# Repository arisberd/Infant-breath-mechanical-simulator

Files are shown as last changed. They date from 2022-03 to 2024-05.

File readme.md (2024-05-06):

# Infant breath mechanical simulator

This project is about building, developing, documenting and using a mechanical breathing simulator. The device simulates airflow conditions observed in either normal infants or those experiencing respiratory diseases. Simulating airflows is used in laboratory conditions for research and experimentation in areas such as flow dynamics, neonatology and respiratory medicine. 

# Features
- High volume and flow accuracy
- Easily expandable in software and hardware (ex. child or adult volumes, advanced respiratory patterns, etc)
- Low construction cost using simple hardware equipment (ex. stepper motors, arduino, etc)

# Main modules
- The volume compartment consists of a calibration syringe for respiratory equipment
- Air flow is produced from a moving carriage by a stepper motor
- Arduino is used for software and data, with a simple interaction with computer's Serial Monitor 
- Some hardware parts are 3d printed, and based on [RepRap Prusa Interation 3](https://reprap.org/wiki/Prusa_i3)

# Documentation
You will find documentation for construction, configuration and usage under [Documentation/doc.md](https://github.com/arisberd/Infant-breath-mechanical-simulator/blob/main/Documentation/doc.md). 

# Version 0.3
This is a developing project, but fully functional on predefined settings. You may encounter problems while using new features or trying to modify functions.

# Contribution
This project started at Pediatric Pulmonology Department of University Hospital of Patras, Greece at 2021. Feel free construct the device, use it or contribute to the project. [Questions and comments](https://github.com/arisberd/Infant-breath-mechanical-simulator/issues) are welcome.

# License
This project is licensed under [GNU GPL v3](https://www.gnu.org/licenses/gpl-3.0.html)

# Credits
We would like to thank major contributors _S.Fouzas, O.Tsakiridis, D.Monopatis_, and also RepRap and Prusa communities.

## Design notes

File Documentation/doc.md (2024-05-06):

# Documentation of Infant Breath Mechanical Simulator

Construction and use

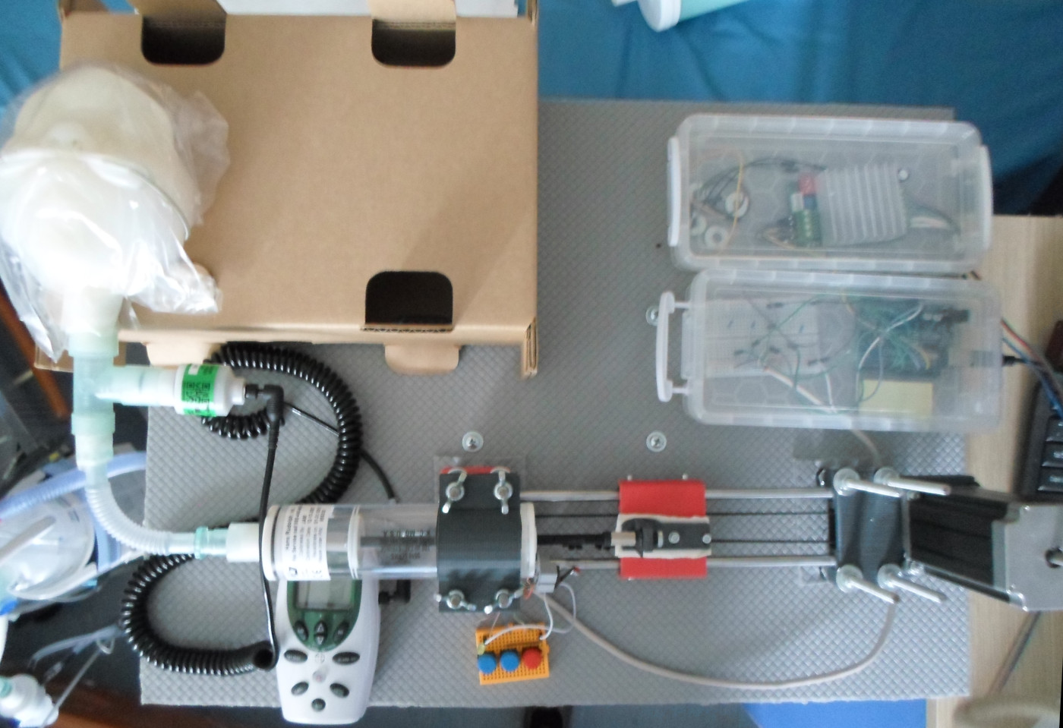
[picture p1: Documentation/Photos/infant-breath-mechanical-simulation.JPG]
 

[https://github.com/arisberd/Infant-breath-mechanical-simulator](https://github.com/arisberd/Infant-breath-mechanical-simulator)

version 0.2

GNU GPL v3

## Table of contents

[TOC]

## General

Infant breath mechanical simulator is a low-tech device designed to facilitate respiratory experiments. Its hardware design is primarily based on RepRap Prusa Interation 3, specifically utilizing its X-axis components. Therefore, the majority of the hardware components are similar to that of a typical 3d printer with a single axis. The device is powered and controlled using  Arduino electronics, providing precise motor movement and enabling computer communication.

# Getting Started

## Project's origin

This is a developing project and was initiated in the Pediatric Department of University Hospital of Patras, Greece in 2021. While this documentation provides comprehensive instructions for construction and use, please be aware that this is a developing project, so issues may arise. 

## Required skills:

To successfully operate this project, you should possess a basic understanding of the following:

* 3d printing: familiarity with 3d printing techniques, equipment and slicing
* Arduino electronics: basic skills of Arduino wiring and program uploading
* Software skills: basic software skills during the first setup, in order to configure the program file

## Community Collaboration

We encourage you to participate in and contribute to the project's development under GPL3 lincense. If you have questions or insights, feel free to contact with [project's community](https://github.com/arisberd/Infant-breath-mechanical-simulator/issues).

### Bill of materials

Electronics:

* Arduino Uno
* Stepper Motor Driver (TB6600A used)
* DC Power supply (24 volt used)
* Breadboard Buttons (2 blue, 1 red)
* Arduino wires, resistants and breadboards

Mechanical Components:

* Stepper Motor 56mm, high torque motor (Wantai NEMA 23 used, 30kg.cm)
* GT2 Gear (40teeth)
* GT2 Belt
* Endstop switch
* Linear bearing 8mm (4 pieces)
* Ball bearing 3mm inner diameter (2 pieces)
* Rods 8mm (2 pieces)
* Wooden frame at least 30 X 40 cm
* Callibration syringe (100ml or 1000ml)

Fasteners:

* M3 bolts and nuts
* M4 bolts and nuts
* M8 bolts and nuts
* A double nut (only at Hole method)

3D printing:

* PLA/PET 3d print filament

## Printing parts

### Overview

In this section you can find 3d-printed STL files required for assembling Infant Breath Mechanical Simulator. These file are available in the `3d_printed_parts/Stl rendered files` folder. These stl files are rendered based on [openscad](http://openscad.org/downloads.html) files, where customization can be made. `Compact_endstop.stl` is made and downloaded by `https://www.thingiverse.com/chri/designs`. 

### 3d Slicing preparation

Before 3d printing, it's vital to prepare the STL file, using a slicing software. We recommend [Prusa Slicer](https://www.prusa3d.com/page/prusaslicer_424/). Printing at `layer height 0.3mm` and `nozzle 0.4mm` was found decent.

### List of 3d-printed files:

* `Axis based on x-end.stl` this file contains 3 models for the one-axis static compartment.
* `x-carriage.stl` is the moving part on the rods.
* `compact_endstop.stl` this part hosts the endstop switch.
* `syringe_attacher_with_flange.stl` and `syringe_attacher_only_the_flange.stl` are used for grapping the syringe with a flange system. Otherwise you can use next file:
* `syringe_attacher_with_hole.stl` this file secures syringe by using a hole and a double nut
* `syringe_base_100ml.stl` mounts a 100ml syringe. You should print at least a pair of them for stability
* `syringe_base_1000ml.stl` mounts a bigger (1000ml) syringe. Again at least a pair of them is needed.

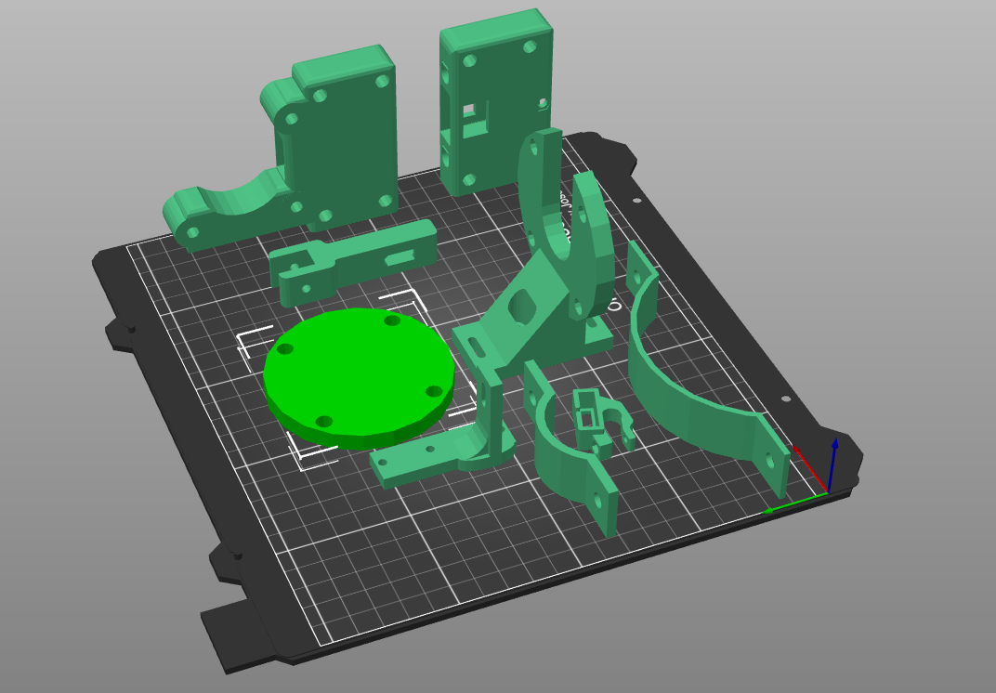
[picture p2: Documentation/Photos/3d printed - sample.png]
 

## Flange or hole method

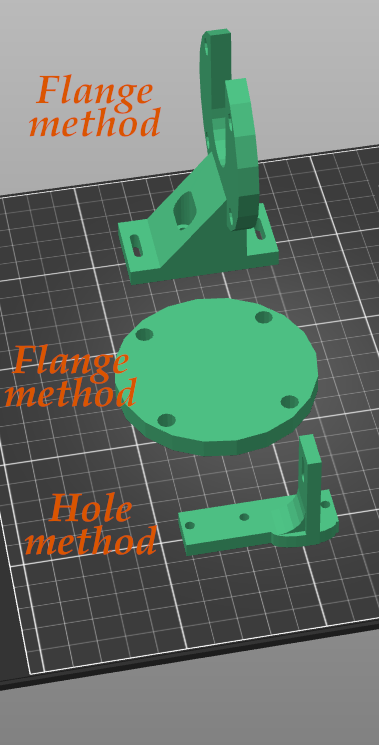
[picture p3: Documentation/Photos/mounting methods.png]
 

There are two methods for attaching the syringe's plunger on the machine: 

* The **flange method** involves using two printed parts to secure plunger's *hand* in place. This method is suitable for calibration syringes where the plunger's hand cannot be detached. Place the plunger's hand between the two 3D-printed parts and use M8 bolts and nuts for securing all together . We used a **1000ml syringe** with this method. 

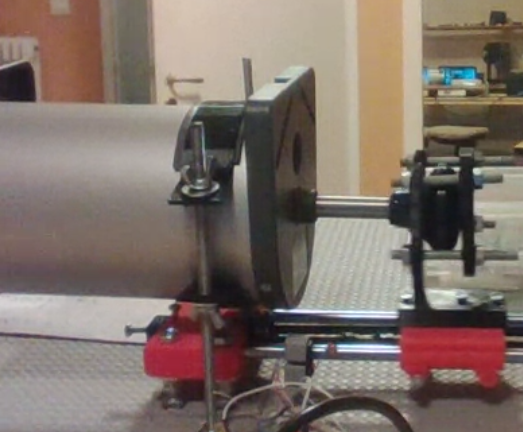
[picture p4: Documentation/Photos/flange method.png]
 

* The **hole method** is used when the syringe's piston has a threaded end, and the plunger's hand can be unscrewed. With this method, only one 3D-printed part is used. A double nut is used to secure the plunger to the 3d print part. We used a **100ml syringe** with this method.

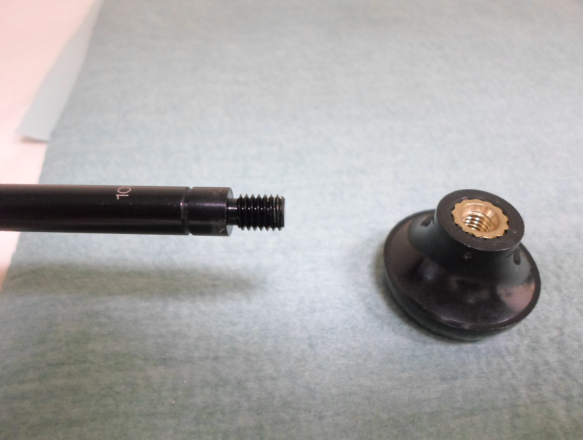
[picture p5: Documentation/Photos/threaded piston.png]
 
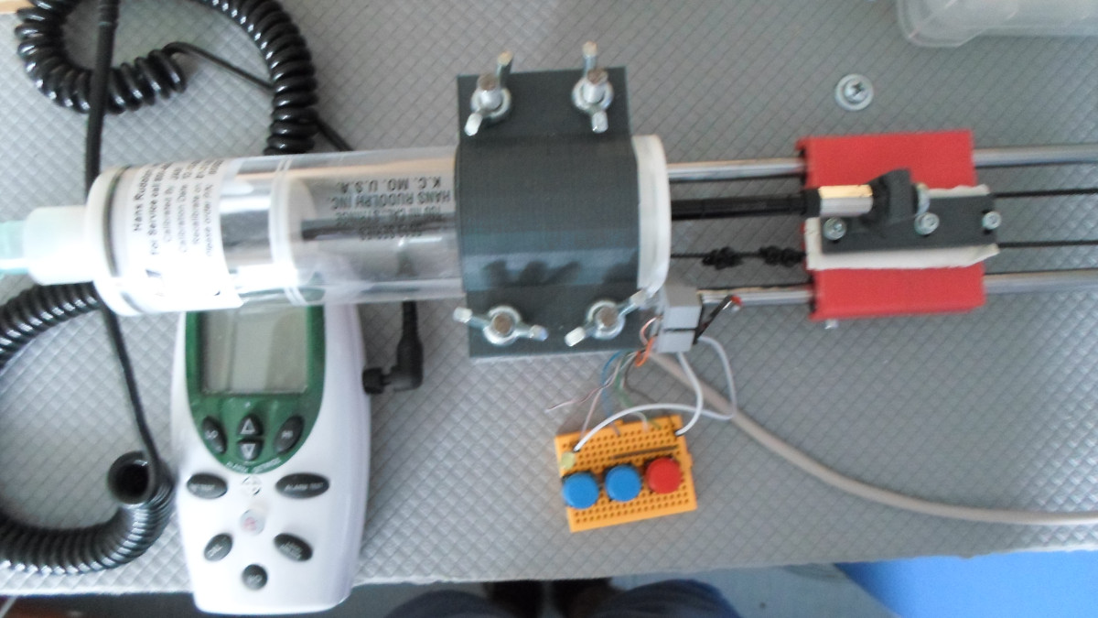
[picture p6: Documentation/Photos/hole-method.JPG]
 

## Electronics

Basic module of the project is an [Arduino Uno](https://store.arduino.cc/products/arduino-uno-rev3). Wiring is shown in the following photo:

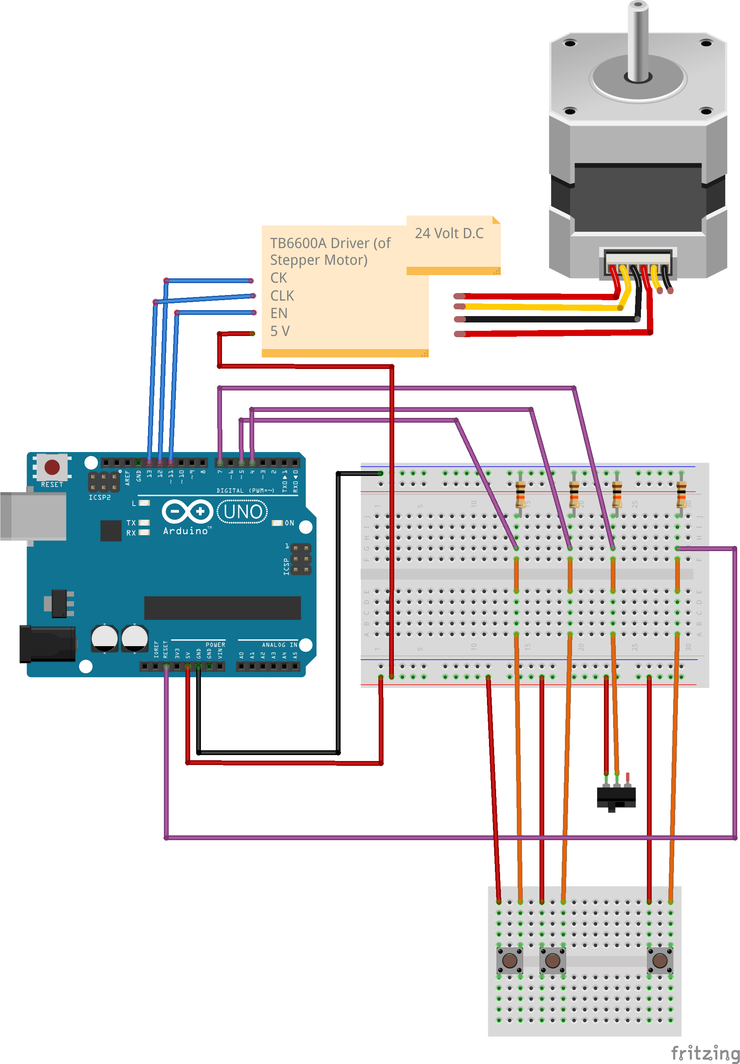
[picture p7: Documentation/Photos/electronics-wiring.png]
 
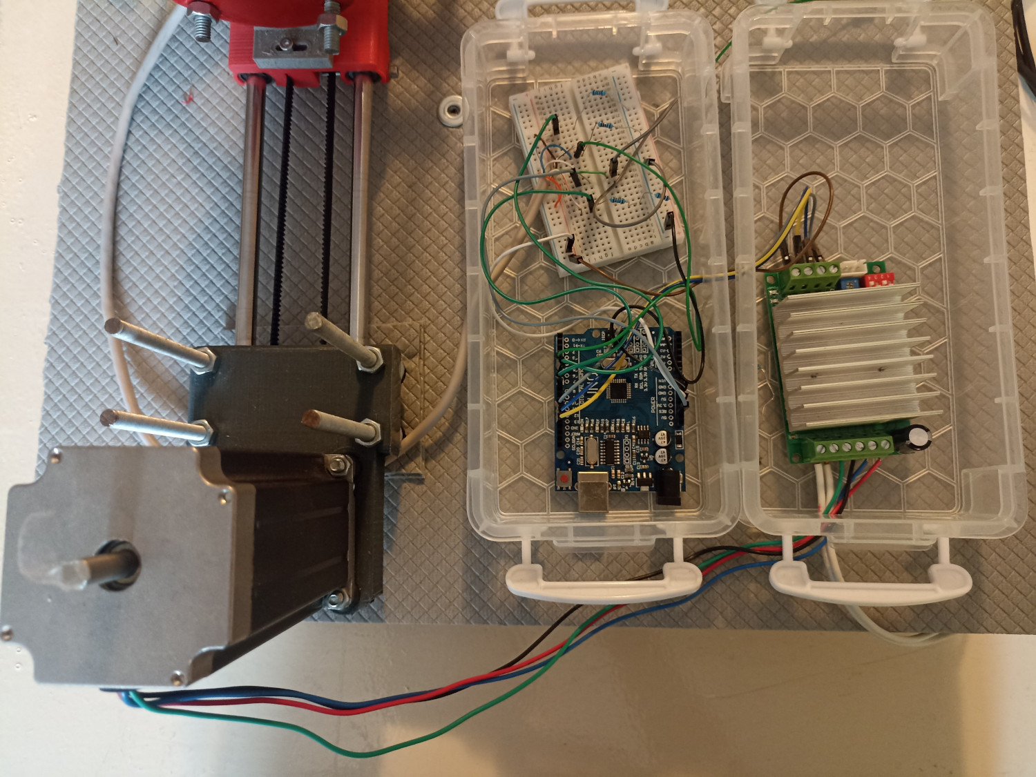
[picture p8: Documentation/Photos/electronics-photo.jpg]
 

* The motor's Driver (TB6600A) is connected at arduino digital pins as shown. Driver also connects to a 24 Volt DC current as well as the Stepper Motor. Be sure to adjust Driver's current sparingly, starting at very low currents and slowly increase at first test. Low current will give low torque to the motor, making it not to move at high speed requirements. High current gives high torch, making driver hot and appling lot of torque at the speed changes. You should also check the microstepping setting. The software's default is 1/8 microstepping (can be changed in software, too). At the following pictures, the arrow show the microstepping switches. We used 8 microsteps. Refer to the datasheet for choosing the correct combination for microstepping.

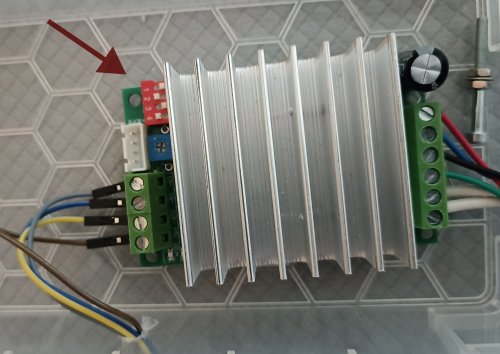
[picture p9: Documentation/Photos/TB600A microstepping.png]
 
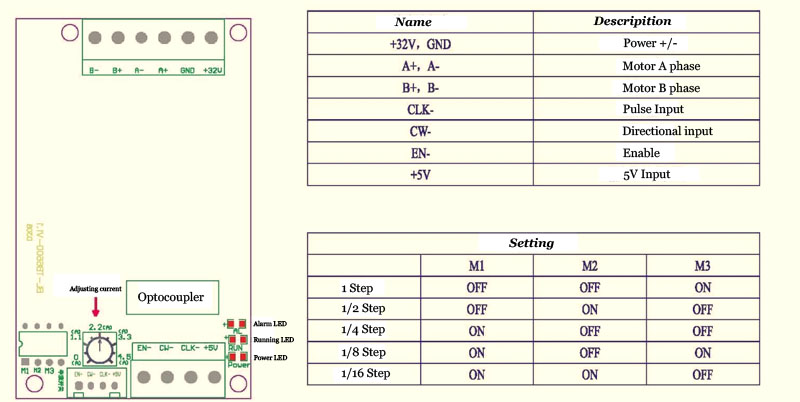
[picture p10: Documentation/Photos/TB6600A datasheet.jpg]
 

* Endstop and Buttons are connected as shown in the picture. A wire extension should be used. Note at endswitch should be connected as open-circuit when not pressed. At the following picture an ethernet cable extension is used (contains 8 wires). Note that the blue button No1 is used for changing rows in the experiment, whereas the blue botton No2 is used for pause. Red button is used for hardware reset, and is connected to the reset button of the arduino.

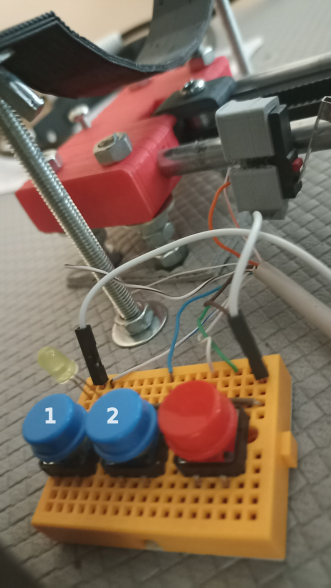
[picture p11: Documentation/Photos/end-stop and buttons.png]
 

Note that both 5 Volt and 24 Volt D.C. circuits are used in this project. 24 Volt is only used at motor's Driver, whereas the 5 Volt is used at almost all modules. The 5 Volt can be produced either by the USB of arduino or direct arduino power. 

## Hardware assembly

NOTE: This project is based on RepRap Prusa Interation 3, as a modified X axis. More instructions based on a x-axis of a 3d printer can be found [here](https://reprap.org/wiki/RepRapPro_Huxley_x_axis_assembly), but use this guide for reference only, as many things are not similar.

1.Frame Setup:

A wooden frame of at least 30 X 40 cm should be used as a base. This frame will hold things together. The way to fix them in place is using M8 bolts and nuts on 3d-printed parts.

2.Thightener:

Start by assembling the `tightener`, which is the small part of the `Axis based on x-end.stl`. This part is crucial for tighten the belt more that can be done by hand. Put a M3 bolt and nut so that the 2 ball bearings hold together at the end of the `tightener`. Put another M3 (or M4) bolt on the other side. This bolt is going to adjust the tension.

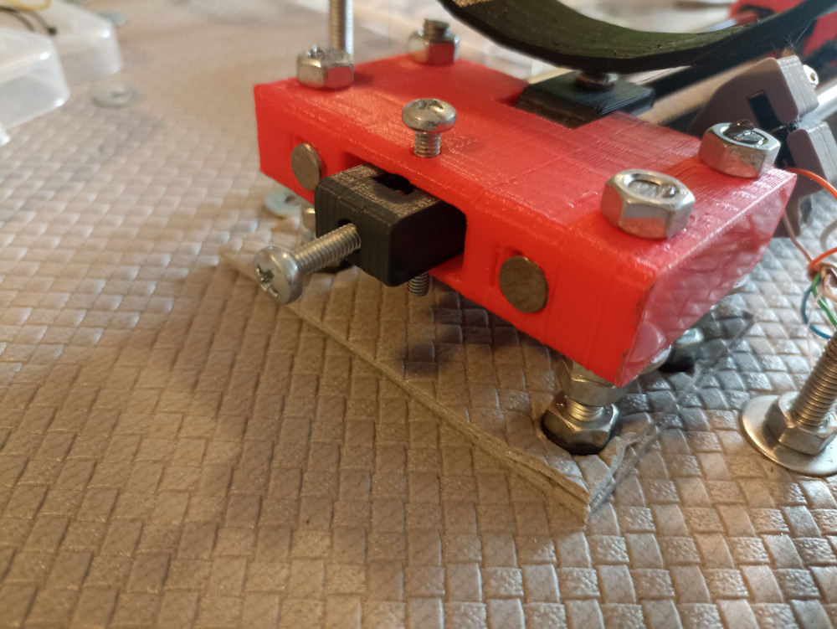
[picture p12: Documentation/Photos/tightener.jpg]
 

3.Carriage assembly and Axis: 

Then you should assembly the `x-carriage.stl`. Belt is attached to this piece so it can be moved up and down on the rods. A second 3d-printed piece will hold the plunger of the syringe, and will be attached upon `carriage`. Start by fitting the 4 linear bearings (3 can also be used) and secure the with M3 bolts and nuts. Attach the one side of the belt at the slot under the `x-carriage.stl`. The other side is to be attached later. Insert the rods to the linear bearing taking care not to damage the bearing. On either side of the rods attach the rest parts of the `Axis based on x-end.stl` by pushing the rods gently. Then you should choose of the two methods of plunger attachment : flange method or hole method. Read also `Flange of hole method`. Take the appropriate 3d-printed part and secure it on `carriage` using three M3 bolts and nuts.  This will appear like the following photo:

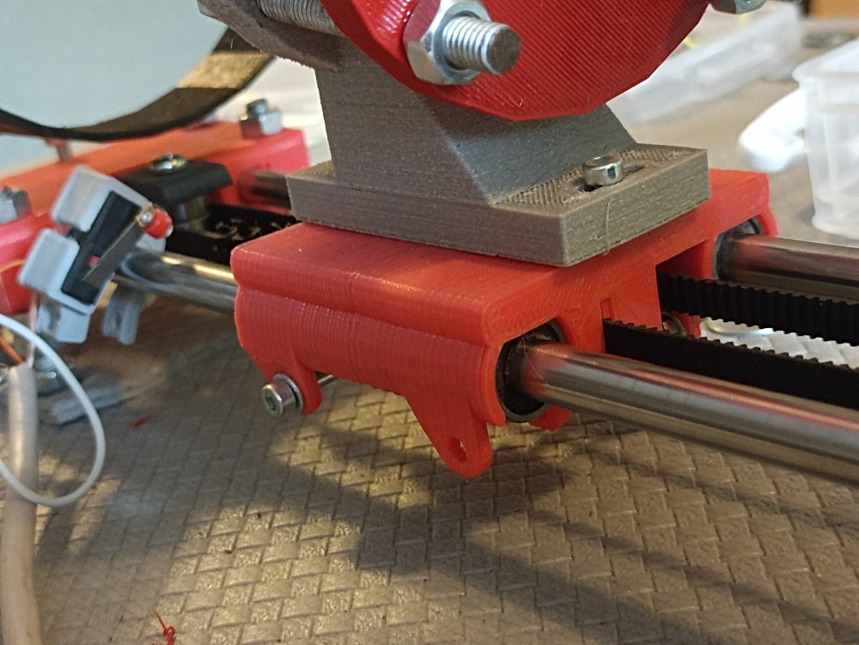
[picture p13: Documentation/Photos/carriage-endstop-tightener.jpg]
 

4.Securing to Wooden Frame:

The two 3d-printed sides of apparatus should be now fixed to the wooden frame. Using M8 bolts and nuts thighten up and fix the in place. 

5.Stepper Motor install:

Fit the 56mm Stepper Motor and secure it using M4 bolts and nuts. Attach the gear and tighten its bolt.

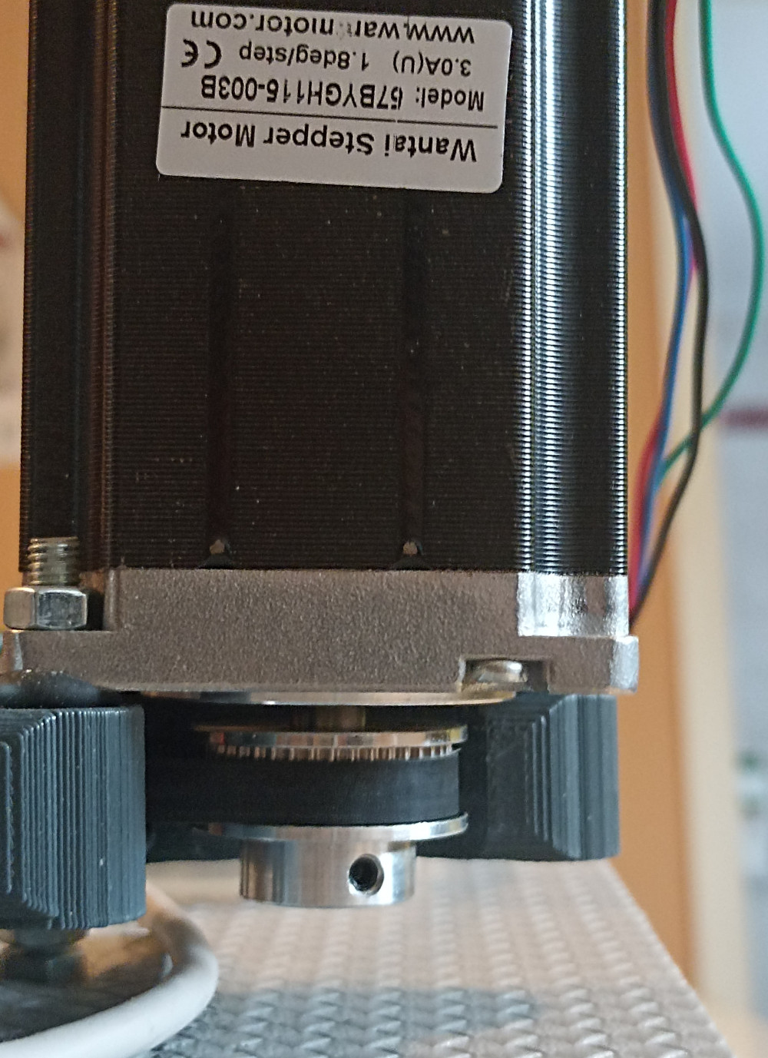
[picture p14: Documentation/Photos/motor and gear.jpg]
 

6.End-stop switch:

Using end-stop switch the system can understand the starting position of the syringe. This is usually a position with little starting air volume. Attach the end-stop switch in the left side of a rod and rotate it so carriage can press the switch button when moved. You can secure the switch with M3 bolts and nuts, or do this job later, in order to test accurate starting volume. 

7.Belt:

Put on the `thightener` at the one side of the apparatus. Pull the belt under the gear at one side and under the `thightener`'s bearings on the other. Then pull belt back under the carriage and fix it properly. Make this first by hand as tight as possible and then tighten more using the side bolt of the `tightener`.

8.Securing syringe:

After reading **Flange or hole method**, choose your printing file between `syringe_base_100ml.stl` and `syringe_base_1000ml.stl`. You will need at least one pair of these. Attach one of the printed files to the wooden frame using M8 bolts and nuts. Take care that bolts are long enough: put the syringe on printed-base and on-top put a second printed-base. Using the same bolt secure wooden frame to both printed parts. You can use a second pair of printed parts to secure syringe in the other side.

 
 

9a. **Flange mode** - Securing the plunger:

Bring all pieces in place: the `syringe_attacher_with_flange.stl` then the handle of the plunger and then the `syringe_attacher_only_the_flange.stl`. These 3 are going to be secured using M8 bolts and nuts. Secure them one by one, taking care not to be very tighted and damage the handle, whereas not being to loose.

9b. **Hole method** - Securing the Plunger:

Things are going to be more stable using the hole method. A long nut at the size of plunger's bolts is going to be needed. First attach this nut at the plunger and then using another bolt, through the 3d printed file syringe_attacher_with_hole.stl. Secure things together.

 

### Beyond Syringe

The syringe can move air to any other compartment. During first setup, an model of infant airway was used as showed in the following photo.

 

### Final hardware aspects

Your hardware setup is ready by this point. Before proceding to software installation and first run, take care to examine all moving parts in order or avoid damage due to misuse:

* Check the belt to be tight enought,

* Move the carriage with your hand slow enough and check if the piston of the syringe move smoothly, in a complete linear movement. It should not take any vertical forces.

* Check the position of carriage when moved and press the end-stop switch, so it does not damage the syringe.

* If using flange method, the handle must be tighted locked between the 3d printed parts and check if as it moves, so it does not get damage. 

## Software

### Arduino IDE

Each specific movement of the carriage will produce distinct respiratory cycle and this is going to be configured through software. Arduino is used not only to control all electronics but also to manage data. To get started, you will need the Arduino software, known as [Arduino IDE](https://www.arduino.cc/en/Guide). This computer software enables to upload programs to Arduino board. Here are the steps:

1. **Download Arduino IDE**: visit the [Arduino IDE download page](https://www.arduino.cc/en/software) to download the software.

2. **Configuration Guide**: Take some time to feel comfortable with Arduino IDE and review the available [documentation](https://www.arduino.cc/en/Guide). This will help you understand how Arduino IDE communicates with Arduino board, including which ports you will need to use and how to select the appropriate Arduino board.

3. **Opening the project's file**: Though Arduino IDE, open the `breath-sim.ino` file of the project. This file contains the code necessary to control arduino board. At this step you don't need to open datasheets that are stored in different files. 

4. **Uploading to Arduino Board**: Connect your Arduino board to your computer using a USB cable. In Arduino IDE, select the correct port and Arduino Board Model and click the *Upload* button. If everything is set corrrectly, then a message will be shown in Arduino IDE terminal to configure a successful upload.

5. **Serial Monitor**: After uploading, you can use Serial Monitor to monitor Arudino's function and send commands. You can open it from Arduino IDE, as long as USB is connected and a prompted upload has been done.

### Data

Data for is stored in seperated files that work as datasheets. By default, `dataleo2.h` is used for this purpose. The data is stored in specific format as outlined in the beggining of datasheet files. These include:

* **VT** (Volume Tidal): this represent the amount of air in **milliliters** (ml) moved in a single breath

* **Ti** (Time of Inspiration): this indicates the time in **milliseconds** of the inspiration phase

* **Te/Ti ratio** (Time of Expiration to Time of Inspiratio ratio): this ratio defines the duration of expiration compared to duration of inspiration, expressed as a percentage. 

All values in datasheets are seperated by commas (,). Each set of these data values forms a row, which corresponds to a specific respiratory cycle. For example in `dataleo2.h`, the first row reads as follows: `80  , 300 , 185 ,`. This configuration results in a respiratory cycle of 80ml, with inspiration time of 300 msec and Te/Ti ratio of 185%. By using mathimatical calculations, you can derive expiration time, which is 555msec in this example, and respiratory rate which is 70/sec. 

You can navigate through different respiratory profiles, by pressing blue button No. 1, which allows you to switch to next rows in the datasheet. In `dataleo2.h` the second row is `80  , 300 , 150 ,`  and differs in Te/Ti ratio only. `Dataleo2.h` datasheet is based on typical breathing parameters for infants.

## Configuration setup before first run

Now its time for your first run! You should check the following list before first run and do some callibration. If you make changes in datasheets or `breath-sim.ino` file, make sure you upload it again. All you will need to configure appear in the first code lines of `breath-sim.ino`. Open it with Arduino IDE and check the values as follows:

### `float steps_to_vol = 3.33 * microsteps * calibration_vol;` 

This values converts number from datasheets (volume) to movement in motor (steps). 3.33 means that 3.33 motor steps are needed for 1 ml air. You may need to change this value if you work with different motor gear (ex. smaller gear will need more steps for the same volume) or different syringe (a bigger syringe will need less steps for the same volume). The correct number you will need to put is found with trial-and-error method. Start by this number if you are using documentation's preset with a 100ml syringe. For smaller gear, try double the value. For bigger syringe, start with 1/15 of the value. Set a number of volume and check how much is moved. Then make corrections and repeat the process. Be careful not to start with big values, because an unexpected fast and long movement can occur.

### `int starting_volume = -6;` 

This is the starting amount of volume you want to set. When the machine runs, it find the end-stop switch and then move -6ml from that place. Change this as it fits your needs

### `int microsteps = 8;` 

This counts the microsteps that is set. If you switch to more microsteps, for example 16, you will need to change this value

### `float calibration_vol = 0.95418 ;` 

This variable serves as fine-tuning calibration parameter. After configuring the correct `steps_to_vol` value, it is important to ensure accurate volume measurements within your setup. To achieve this, you will require a pneumotachograph, a seperated device used for precise volume measurements. Follow these steps:

1. Connect a pneumotachograph to the syringe.

2. Conduct accurate volume measurements with the pneumotachgraph and compare them to the predefined target volumes of datasheet. For instance, if your measurements read `78ml` while the target volume is `80ml`, calculate the ratio 80/78 = 1,025641026.

3. Set calculated ratio as a new value for `calibration_vol` and upload the program on Arduino.

4. Repeat this process until your measurements align closely with the target volumes. Keep in mind that the second time you will need to multiply the new factor with the last one used.

### Arduino I/O pin connections 

Arduino I/O pin connections are set in the begining of `breath-sim.ino`. In the begininng of breath-sim.ino file, you'll find the default configuration as shown before. If, at any point, you need to modify these pin connections to accommodate changes in your electronic wiring, you can easily make these adjustments in this section of the code. Be sure to save and update the program on Arduino.

## Checkup list before first run

You are ready for the first run. Before you proceed, make sure to perform the following checks:

* **Begin with small volumes** and set small float `steps_to_vol` values to prevent potential damage due to high speed moves.

* Verify that all hardware **nuts are tightened** securely.

* Make sure that **carriage does not come in contact** with any part of the syringe or end stop during its movement.

* Make sure that **syringe piston** is moved smoothly and is properly aligned.

* Note that **end-stop-switch** can be pressed by carriage on its movement.

* Initially, use **low current setting** on the motor driver and increase it gradually after the first use.

* **Plug arduino USB** (5V)  or 9V current and be prepared to connect the 24V Motor's current when prompted.

* Open **Serial Monitor** to monitor status and output from the Arduino.

## Using Infant Breath Mechanical Simulator 

You can make experiments with air movement using Infant Breath Mechanical Simulator. Set up a datasheet according to your needs. After a prompt upload, you will see a welcome message in Serial Monitor. Before starting the experiment you will be asked to plug in 24V current and press the Blue button No 1. While running, you are going to read messages of status in Serial Monitor.

* **Blue Button No 1**: Press this button to switch to another row. You will face a change in movement pattern. By default, it advances to the next row until the last and loops back to the beginning. You can manually switch to a specific row but entering the row number in the Serial Monitor and pressing enter. Then, the next time you press Blue Button No 1, it will get to that row.

* **Blue Button No 2**: Use this button to pause experiment. You can resume it with the same button later as needed.

* **Red Button**: This button serves as a hardware reset. It performs the same function as unplugging and re-plugging the Arduino USB connection, effectively restarting the program.

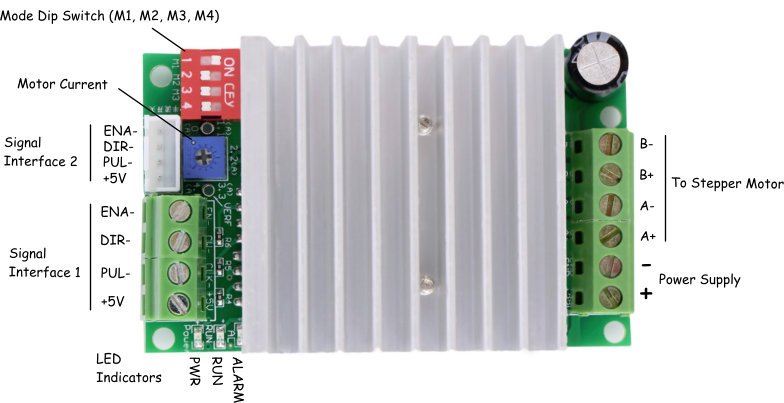
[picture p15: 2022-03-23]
Hardware/Datasheets/TB6600A - Layout01.jpg

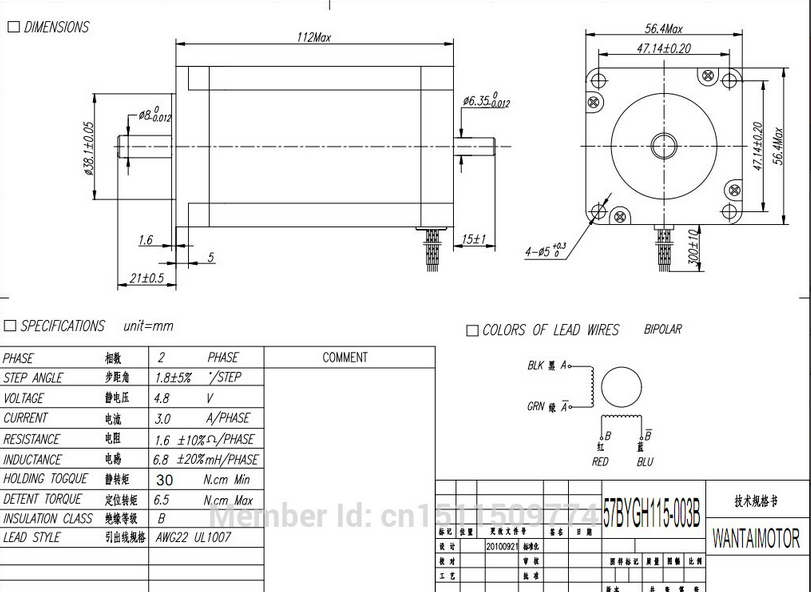
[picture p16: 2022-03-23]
Hardware/Datasheets/Stepper.png

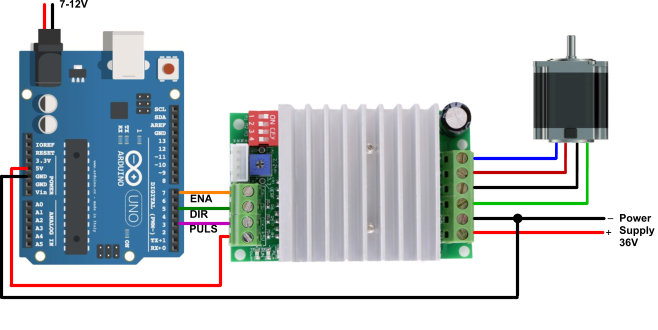
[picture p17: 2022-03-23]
Hardware/Datasheets/TB6600A - Layout04.jpg

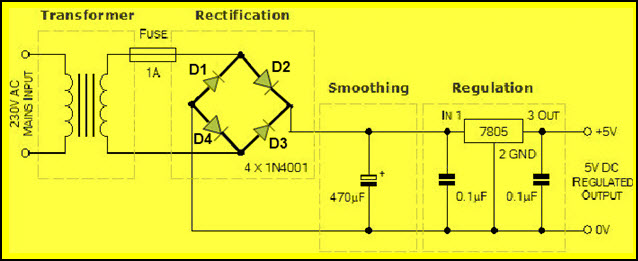
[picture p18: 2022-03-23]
Hardware/Datasheets/AC-to-DC-Converter-Circuit.jpg

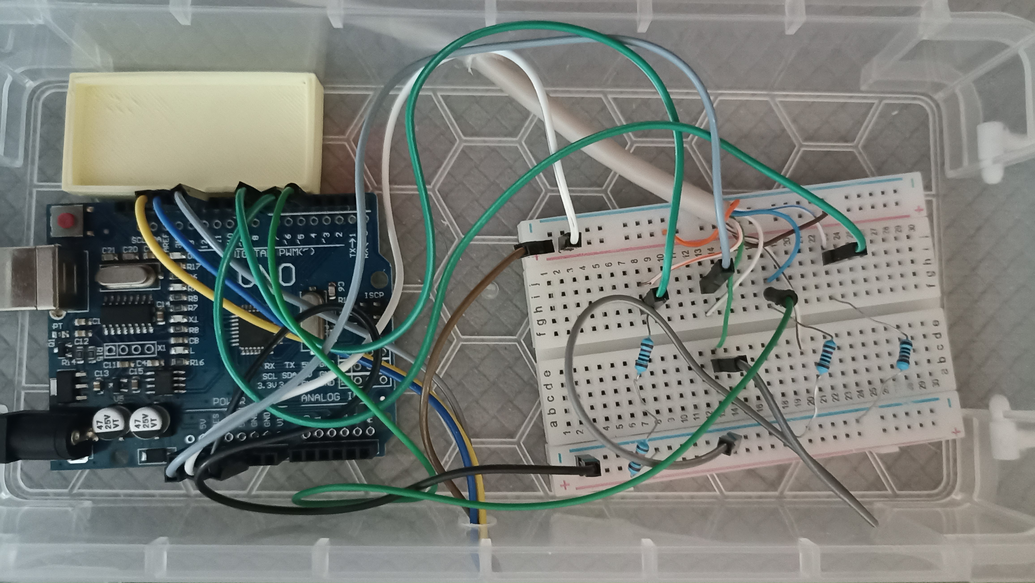
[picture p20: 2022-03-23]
Photo and Video/electronics1.jpg

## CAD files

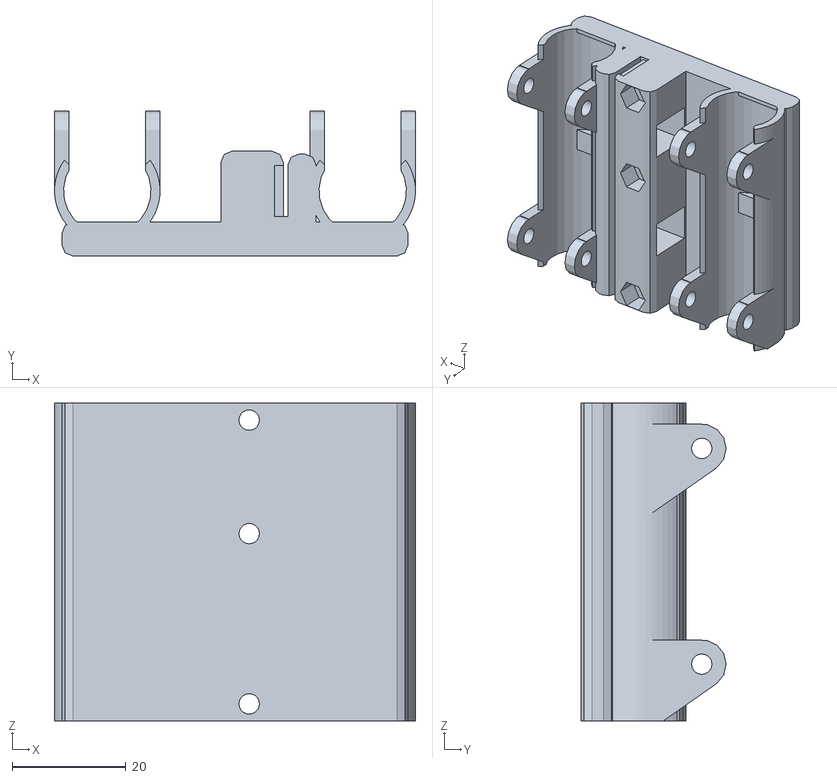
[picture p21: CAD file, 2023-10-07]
3d_printed_parts/Stl rendered files/x-carriage.stl
63.6 x 25.6 x 56.0

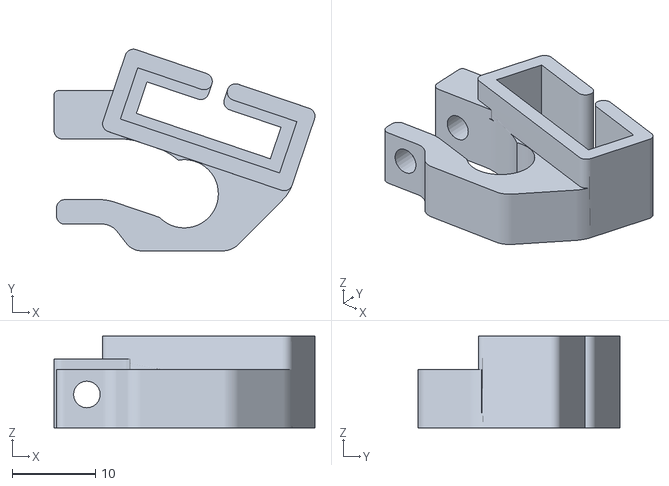
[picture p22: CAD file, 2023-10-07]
3d_printed_parts/Stl rendered files/compact_endstop.stl
31.4 x 24.2 x 11.0

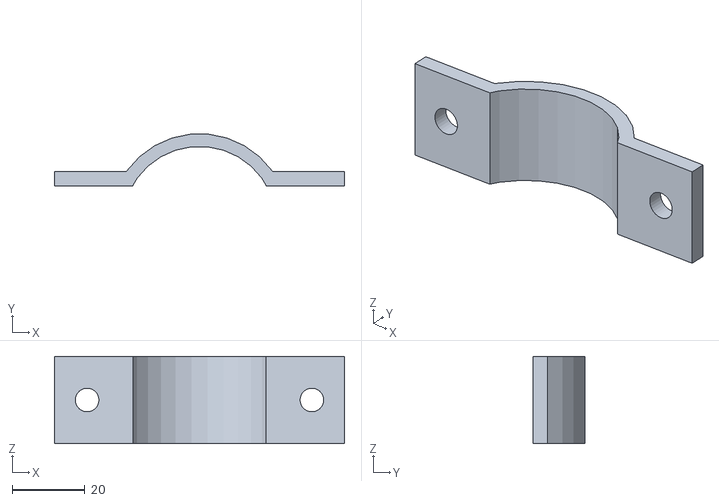
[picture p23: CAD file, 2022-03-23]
3d_printed_parts/Stl rendered files/syringe_base_100ml.stl
80.0 x 14.2 x 24.0

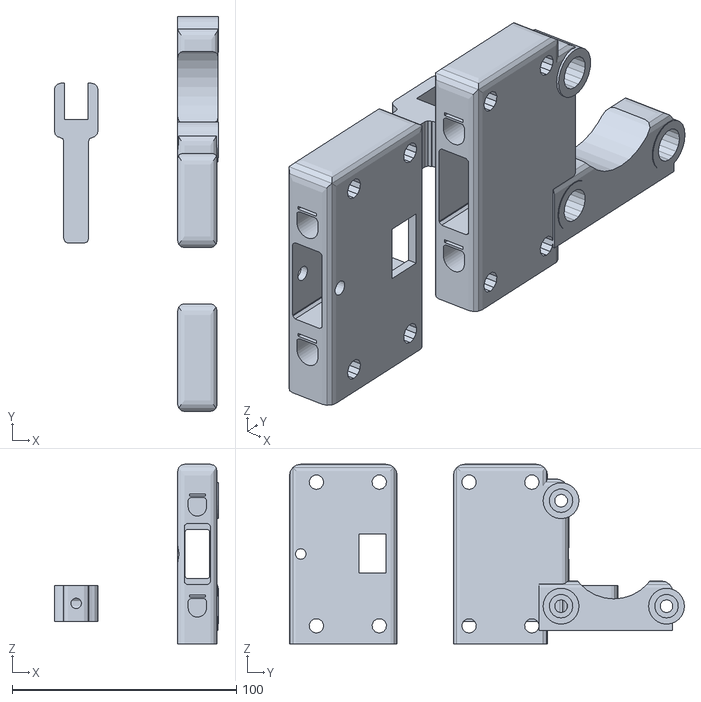
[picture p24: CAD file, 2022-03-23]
3d_printed_parts/Stl rendered files/Axis based on x-end.stl
73.2 x 176.0 x 80.0

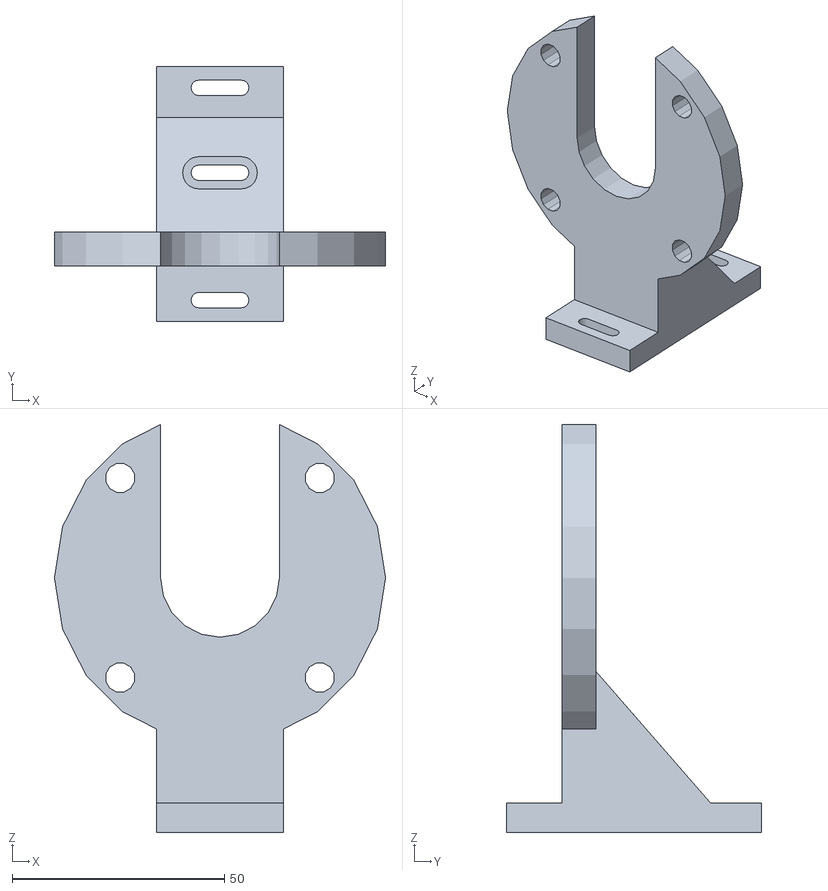
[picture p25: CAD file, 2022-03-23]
3d_printed_parts/Stl rendered files/syringe_attacher_with_flange.stl
78.0 x 60.0 x 96.1

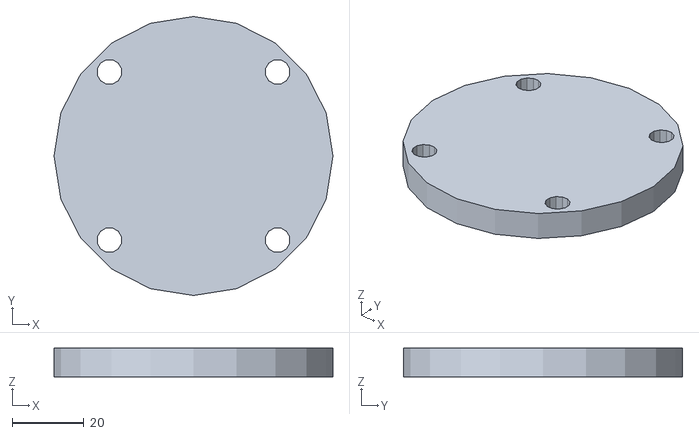
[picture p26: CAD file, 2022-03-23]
3d_printed_parts/Stl rendered files/syringe_attacher_only_the_flange.stl
78.0 x 78.0 x 8.00

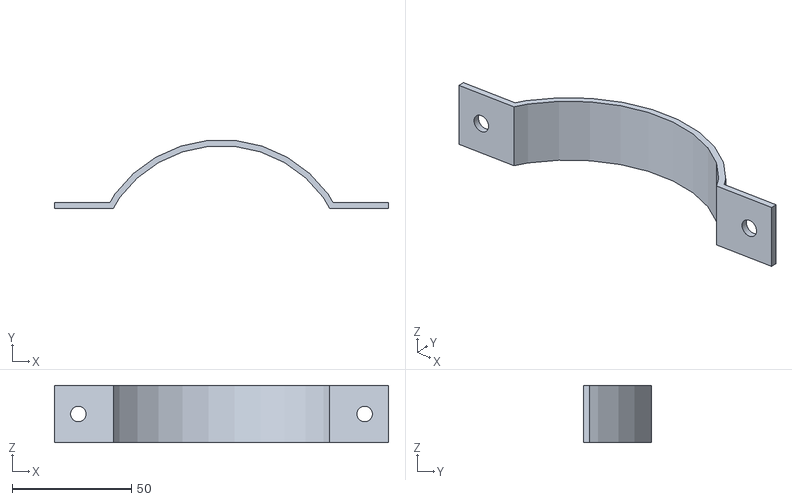
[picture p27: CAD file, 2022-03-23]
3d_printed_parts/Stl rendered files/syringe_base_1000ml.stl
140.0 x 28.6 x 24.0

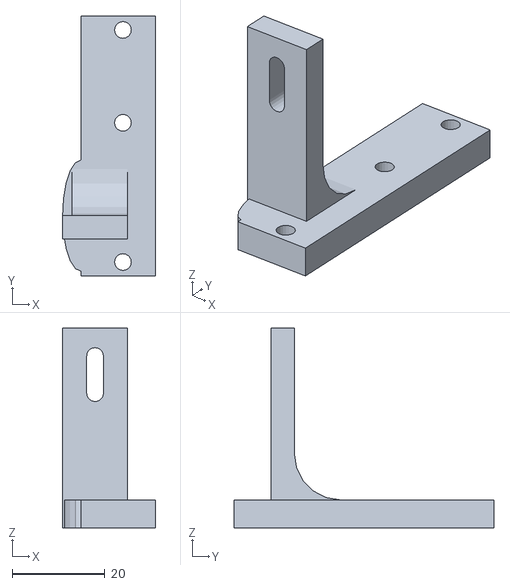
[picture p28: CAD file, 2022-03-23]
3d_printed_parts/Stl rendered files/syringe_attacher_with_hole.stl
20.0 x 56.0 x 43.0

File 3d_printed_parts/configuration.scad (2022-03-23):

// PRUSA iteration3
// Configuration file
// GNU GPL v3
// Josef Průša <josefprusa@me.com>
// Václav 'ax' Hůla <axtheb@gmail.com>
// http://www.reprap.org/wiki/Prusa_Mendel
// http://github.com/josefprusa/Prusa3

include <inc/metric.scad>;
include <inc/conf_bushing.scad>;

// Custom settings here, tailor to your supplies and print settings

// Extruder settings **********************************************************
// Don't forget to set your slicer's extruder settings to match the values you
// enter here.

layer_height = 0.3;
// Width over thickness determines how wide the plastic will be when extruded
// onto the object that is being printed. width_over_thickness is multiplied
// by the layer_height to calculate this width. i.e. If your layer_height is
// set to 0.3 mm and your width_over_thickness is set to 2.2, the resulting
// width will be 0.66 mm.
width_over_thickness = 1.33; // modified by otsakir for calibrating // 2.2;

// Select your belt type ******************************************************

// T2.5
//belt_width = 6.5;  //add 0.5 to actual width
//belt_tooth_distance = 2.5;
//belt_tooth_ratio = 0.75;
//belt_thickness = 0.8;

// T5 (strongly discouraged)
//belt_width = 6.5;
//belt_tooth_distance = 5;
//belt_tooth_ratio = 0.75;
//belt_thickness = 0.8;

// HTD3
//belt_width = 9.5;
//belt_tooth_distance = 3;
//belt_tooth_ratio = 0.75;
//belt_thickness = 1.75;

// MXL
//belt_width = 6.5;
//belt_tooth_distance = 2.032;
//belt_tooth_ratio = 0.64;
//belt_thickness = i have no idea;

// GT2 
// there is bunch of GT2 belts with different tooth-to-tooth distance
// this one is most common in reprap world
// adjust to your needs.
belt_width = 6.5;
belt_tooth_distance = 2;
belt_tooth_ratio = 0.5;
belt_thickness = 0.8;

// Choose bearing/bushing configuration ***************************************
// conf_b_* are in inc/conf_bushing.scad

bushing_xy = conf_b_lm8uu;
bushing_z = conf_b_lm8uu;
// for longer bearings use one shorter in x-carriage to make place for belt attachment
// by default use same as xy
bushing_carriage = bushing_xy;


// Select idler bearing size **************************************************
// bearing_* are in inc/conf_bushing.scad

idler_bearing = bearing_623;

// Select carriage lenght ******************************************************
// 30 for single carriage extruder (two holes with centers 30mm apart)
// 50 for wade or single with fan (three holes, 30-20)
// 80 for full length carriage (four holes, 30-20-30)

carriage_l_base = 50;


// Fillets ********************************************************************
// fillets are rounded corners of boxes. The right engineering term is probably radius
// but cad software calls it fillet.
// mostly cosmetic, except z axis.
// 0 = no fillets
// 1 = fillet
// 2 = chamfer (cut the edges at 45deg. angle)
// Please do put only parts with fillets on sale, other options are not really tested

use_fillets = 1;

// set to 0 for single plate (affects z axis and screws that attach RP parts to frame)
i_am_box = 0;

// if you do your own plate and can move bottom Z screws 5mm up set this to 0 to
// get stronger motor mount. Only for i_am_box = 0
i_want_to_use_single_plate_dxf_and_make_my_z_weaker = 1;


// Radius of long threaded rod on Y frame

// Affects y-axis-corner (both box and single plate)
// and y-axis-bracket (box only)

//Use 5.4 for M10 or 4.4 for M8
y_threaded_rod_long_r = 5.4;


// Thickness of the boards that make the box frame.

// in y-axis-corner it governs the height of the corners by adjusting the
// distance between ground and M10 threaded rod. (both box and single plate)

// For box model, the parts that hold Z smooth rod have one hole from front
// and one from side, and this setting makes sure that the screw from side
// is in the center of the plank.

// Use 12 for single plate
// or 20 if you want to use the Y lm8uu holders
// (extras/bearing-holder-single-plate-y)
board_thickness = 20;

// Segments of small holes. some poeple claim that a low value makes them easier to print.
small_hole_segments=20;

// functions
include <inc/functions.scad>;
include <inc/settings.scad>;

// These constants define the geometry of the doc/complete-printer.scad
bed_x_size=225;
bed_y_size=225;
x_smooth_rod_length=380+board_thickness*2;
y_smooth_rod_length=400;
z_smooth_rod_length=320;

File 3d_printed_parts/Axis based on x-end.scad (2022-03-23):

//Infant-breath-mechanical-simulator
//https://github.com/arisberd/Infant-breath-mechanical-simulator
//version 0.2
//GNU GPL v3

//Axis based on x-end of Prusa iteration3 
// http://www.reprap.org/wiki/Prusa_Mendel
// http://github.com/josefprusa/Prusa3
//GNU GPL v3

//For the purposes of the project
motor_thickness_add=8;//thickenning the motor's arm
motor_arm_y_lengthen=2.5; //lengthen the motor's arm module at y axis


// ThingDoc entry
/**
 * @id xMotorEnd
 * @name X Axis Motor End
 * @category Printed
 */
 
/**
 * @id xIdlerEnd
 * @name X Axis Idler End
 * @category Printed
 */
 
include <configuration.scad>
use <bushing.scad>
use <inc/bearing-guide.scad>
use <y-drivetrain.scad>

//height and width of the x blocks depend on x smooth rod radius
x_box_height = 52 + 2 * bushing_xy[0];
x_box_width = (bushing_xy[0] <= 4) ? 17.5 : bushing_xy[0] * 2 + 9.5;
bearing_height = max ((bushing_z[2] > 30 ? x_box_height : (2 * bushing_z[2] + 8)), x_box_height);


module x_end_motor(){

    mirror([0, 1, 0]) {

        x_end_base([3, 3, min((bushing_xy[0] - 3) * 2, 3), 2], len=42, offset=-5, thru=false);

        
        
        translate([0, -z_delta - 2-motor_arm_y_lengthen, 0]) difference(){
            union(){
                intersection() {
                    translate([-15, -34, 30]) cube([20, 60+12, x_box_height+8], center = true);
                    union() {
                        translate([-14, -16 + z_delta / 2+motor_arm_y_lengthen, 24+6]) cube_fillet([17.5, 10.5 + z_delta+motor_arm_y_lengthen, 55+12], center = true, vertical=[0, 0, 3, 3], top=[0, 3, 6, 3], $fn=16);
                        //lower arm holding outer stepper screw
                        translate([-10.25, -34, 9]) intersection(){
                            translate([-motor_thickness_add/2, -5+motor_arm_y_lengthen, -5]) cube_fillet([10+motor_thickness_add, 37+20+motor_arm_y_lengthen, 28], center = true, vertical=[0, 0, 0, 0], top=[0, 3, 5, 3]);
                            translate([-10/2-motor_thickness_add, 10-30, -26-30-5]) rotate([45, 0, 0]) cube_fillet([10+motor_thickness_add, 60+30, 60+30+motor_arm_y_lengthen*5], radius=2);
                        }
                    }
                }
                
                translate([-16-motor_thickness_add+1-0.5, -32-8, 30.25]) rotate([90, 0, 0])  rotate([0, 90, 0]) nema30(places=[1, 0, 1, 1], h=11+motor_thickness_add-1);
            }

            // motor screw holes
            translate([21-5, -21-11, 30.25]){
                // belt hole
                    translate([-30, 11, -0.25]) cube_fillet([11, 36, 22], vertical=0, top=[0, 1, 0, 1], bottom=[0, 1, 0, 1], center = true, $fn=4);
                //motor mounting holes
                translate([-29.5, -8, 0]) rotate([0, 0, 0])  rotate([0, 90, 0]) nema30(places=[1, 1, 0, 1], holes=true, shadow=5.5, $fn=small_hole_segments, h=8);
            }
            //substracts a cylinder for big gears
            translate([21-5, -21-11, 30.25]) translate ([-60,-8,0]) rotate ([0,90,0]) cylinder (h=100, d=40.5);
        }
        //smooth rod caps
        //translate([-22, -10, 0]) cube([17, 2, 15]);
        //translate([-22, -10, 45]) cube([17, 2, 10]);
    }
}

module x_end_base(vfillet=[3, 3, 3, 3], thru=true, len=40, offset=0){

    difference(){
        union(){
            translate([-10 - bushing_xy[0], -10 + len / 2 + offset, 30]) cube_fillet([x_box_width, len, x_box_height+20], center=true, vertical=vfillet, top=[5, 3, 5, 3]);
            //z-axis module is not needed for the project
            /*!translate([0, 0, 4 - bushing_xy[0]]) {
                //rotate([0, 0, 0]) translate([0, -9.5, 0]) 
                translate([z_delta, 0, 0]) render(convexity = 5) linear(bushing_z, bearing_height);
                // Nut trap
                translate([-2, 18, 5]) cube_fillet([20, 14, 10], center = true, vertical=[8, 0, 0, 5]);x
                //}
            }*/
        }
            
             
       
        
        /*
        // here are bushings/bearings
        translate([z_delta, 0, 4 - bushing_xy[0]]) linear_negative(bushing_z, bearing_height);
*/
        
        //holes for mounting at the base, diameter 6.5mm
        translate ([0,-8,-2]) rotate([0,90,0]) cylinder (h=50, d=6.5, center=true);
        translate ([0,+20,-2]) rotate([0,90,0]) cylinder (h=50, d=6.5, center=true);
        translate ([0,-8,x_box_height+2]) rotate([0,90,0]) cylinder (h=50, d=6.5, center=true);
        translate ([0,+20,x_box_height+2]) rotate([0,90,0]) cylinder (h=50, d=6.5, center=true);
        
        // belt hole
        translate([-14 - xy_delta / 2, 22 - 9 + offset, 30]) cube_fillet([max(idler_width + 2, 11), 55, 27], center = true, vertical=0, top=[0, 1, 0, 1], bottom=[0, 1, 0, 1], $fn=4);

        //smooth rods
        translate([-10 - bushing_xy[0], offset, 0]) {
            if(thru == true){
                translate([0, -11, 6]) rotate([-90, 0, 0]) pushfit_rod(bushing_xy[0] * 2 + 0.2, 50);
                translate([0, -11, xaxis_rod_distance+6]) rotate([-90, 0, 0]) pushfit_rod(bushing_xy[0] * 2 + 0.2, 50);
            } else {
                translate([0, -7, 6]) rotate([-90, 0, 0]) pushfit_rod(bushing_xy[0] * 2 + 0.2, 50);
                translate([0, -7, xaxis_rod_distance+6]) rotate([-90, 0, 0]) pushfit_rod(bushing_xy[0] * 2 + 0.2, 50);
            }
        }
        translate([0, 0, 5 - bushing_xy[0]]) {  // m5 nut insert
            translate([0, 17, 0]) rotate([0, 0, 10]){
                //rod
                translate([0, 0, -1]) cylinder(h=(4.1 / 2 + 5), r=3, $fn=32);
                //nut
                translate([0, 0, 9]) cylinder(r=4.6, h=14.1, center = true, $fn=6);

            }
        }
    }
    //threaded rod
    //translate([0, 17, 0]) cylinder(h = 70, r=2.5+0.2);
}

module x_end_idler(){
    difference() {
        x_end_base(len=48 + z_delta / 3, offset=-10 - z_delta / 3);
        // idler hole
        translate([-20, -15 - z_delta / 2, 30]) {
            rotate([0, 90, 0]) cylinder(r=m4_diameter / 2, h=33, center=true, $fn=small_hole_segments);
            translate([15 - 2 * single_wall_width, 0, 0]) rotate([90, 0, 90]) cylinder(r=m4_nut_diameter_horizontal / 2, h=3, $fn=6);

        }
        translate([-6 - x_box_width, 11, 29.5 - (max(idler_width, 16) / 2)]) cube([x_box_width + 1, 12, 1.5 + max(idler_bearing[0], 16)]);
    }
        %translate([-14 - xy_delta / 2, -9, 30.5 - (max(idler_width, 16) / 2)]) x_tensioner();
}

module x_tensioner(len=68, idler_height=max(idler_bearing[0], 16)) {
    idlermount(len=len, rod=m4_diameter / 2 + 0.5, idler_height=idler_height, narrow_len=47, narrow_width=idler_width + 2 - single_wall_width);
}


translate([-40, 0, 4 - bushing_xy[0]]) x_tensioner();
translate([0, -80, 0]) mirror([1, 0, 0]) x_end_idler(thru=true);


difference () {
    translate([-50, 0, 0]) mirror([1, 0, 0]) translate([-50, 0, 0]) x_end_motor();
//tester
//    translate ([0,-22,0]) cube ([60,70,200],center = true);
//    translate ([0,-10,71]) cube ([60,70,20],center = true);
//    translate ([0,-10,-12]) cube ([60,170,20],center = true);
    
}


module pushfit_rod(diameter, length){
    cylinder(h = length, r=diameter/2, $fn=30);
    translate([0, -diameter/4, length/2]) cube_fillet([diameter, diameter/2, length], vertical = [0, 0, 1, 1], center = true, $fn=4);

    translate([0, -diameter/2-1.2, length/2]) cube([diameter - 1, 1, length], center = true);
}

/*bearing guides
if (idler_bearing[3] == 1) {  // bearing guides
    translate([-39,  -60 - idler_bearing[0] / 2, 4 - bushing_xy[0]]) rotate([0, 0, 55]) {
        render() bearing_assy();
    }
}
*/

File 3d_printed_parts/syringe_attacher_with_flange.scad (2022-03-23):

//Infant-breath-mechanical-simulator
//https://github.com/arisberd/Infant-breath-mechanical-simulator
//version 0.2
//GNU GPL v3

//syringe_attacher_with_flange.scad is used to mount any syringe. 

base_thickness= 7;
attacher_thickness=8; 
height = 60; //Distance between the top of the x-carriage.scad and the piston of the syringe
y_position = 13; //y offset of the attacher
base_x = 20+10; //dimension of the base
base_y = 56+4; //dimension of the base
strut_y = 27; //dimension of the strut
strut_z = height-22; //dimension of the strut

//uncomment the following line to produce only the flange
//!flange(diameter_max=50+18+2+8, diameter_mid=50+5, diameter_min = 28, thickness=attacher_thickness,hole_diameter=7,open=false);


module cylinder_double (r,h,x=0,y=0,z=0) {
   hull() {
    translate([x/2,y/2,z/2]) cylinder(r = r, h = h);
    translate([-x/2,-y/2,-z/2]) cylinder(r = r, h = h );
}
}


//Module flange
//diameter_min = the diameter in witch the handle fits
//diameter_mid = the diameter of the handle. The bolts are places between this and the diameter_max
//hole_diameter = diameter of each hole
//hole_degrees = the degrees of the circle at flange that the holes appear
//open = true, makes an open flange without lid
module flange(diameter_max,diameter_mid,diameter_min,thickness,hole_diameter, hole_degrees=45, open=false) {
    difference () {
    cylinder (d=diameter_max,h=thickness);
    //4holes
    rotate([0,0,hole_degrees]) translate([(diameter_max-diameter_mid)/4+diameter_mid/2,0,0]) cylinder(d=hole_diameter,h=thickness,$fn=12);
    rotate([0,0,-hole_degrees]) translate([(diameter_max-diameter_mid)/4+diameter_mid/2,0,0]) cylinder(d=hole_diameter,h=thickness,$fn=12);
    rotate([0,0,180-hole_degrees]) translate([(diameter_max-diameter_mid)/4+diameter_mid/2,0,0]) cylinder(d=hole_diameter,h=thickness,$fn=12);  
    rotate([0,0,180+hole_degrees]) translate([(diameter_max-diameter_mid)/4+diameter_mid/2,0,0]) cylinder(d=hole_diameter,h=thickness,$fn=12);        
    //the medium diameter cylinder
    %cylinder (d=diameter_mid,h=thickness);
    rotate([0,0,180]) if (open) { //if open=true, then the 2nd piece is made, with min hole
        cylinder (d=diameter_min,h=thickness);
        translate([diameter_max/2,0,0]) cylinder_double(r=diameter_min/2,h=thickness,x=diameter_max);
    }
    }
    %cylinder(h=thickness,d=1); //for centering purposes   
    
}



$fn=20;
difference () {
    union() {
//base on carriage
difference () {
    union() {
        //base rectangular 
        translate([-base_x/2,0,0]) cube ([base_x,base_y,base_thickness]);
        //base strut
            CubePoints = [
                [  base_x/2,  y_position+attacher_thickness,  0 ],  //0
                [ base_x/2,  y_position+attacher_thickness+strut_y,  0 ],  //1
                [ -base_x/2,  y_position+attacher_thickness+strut_y,  0 ],  //2
                [  -base_x/2,  y_position+attacher_thickness,  0 ],  //3
                [  base_x/2,  y_position+attacher_thickness, strut_z ],  //4
                [ base_x/2,  y_position+attacher_thickness+strut_y,  base_thickness ],  //5
                [ -base_x/2,  y_position+attacher_thickness+strut_y,  base_thickness ],  //6
                [  -base_x/2,  y_position+attacher_thickness, strut_z ]]; //7
  
            CubeFaces = [
                [0,1,2,3],  // bottom
                [4,5,1,0],  // front
                [7,6,5,4],  // top 
                [5,6,2,1],  // right
                [6,7,3,2],  // back
                [7,4,0,3]]; // left
  
            polyhedron( CubePoints, CubeFaces );
        
    }
        translate([0,3+2,0]) rotate (0,90,0)  cylinder_double (r=1.8,h=base_thickness,x=10);
        translate([0,3+30+2,0]) rotate (0,90,0)  cylinder_double (r=1.8,h=base_thickness,x=10);
        //2nd has another hole for the strut
        translate([0,3+30+2,base_thickness]) rotate (0,90,0)  cylinder_double (r=1.8+2,h=base_thickness*10,x=10);
        translate([0,3+50+2,0]) rotate (0,90,0)  cylinder_double (r=1.8,h=base_thickness,x=10);
};

//neck
union() {
    translate ([-base_x/2,y_position,0]) cube ([base_x,attacher_thickness,40]);
    translate([0,y_position+attacher_thickness,height]) rotate([90,90,0]) flange(diameter_max=50+18+2+8, diameter_mid=50+5, diameter_min = 28, thickness=attacher_thickness,hole_diameter=7,open=true);
}
}
translate([-base_x/2,0,-100]) cube([base_x,base_y,100]);
}

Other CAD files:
3d_printed_parts/syringe_attacher_with_hole.scad
3d_printed_parts/bushing.scad
3d_printed_parts/inc/bearing-guide.scad
3d_printed_parts/inc/conf_bushing.scad
3d_printed_parts/inc/functions.scad
3d_printed_parts/inc/metric.scad
3d_printed_parts/inc/settings.scad
3d_printed_parts/syringe_base_1000ml.scad
3d_printed_parts/syringe_base_100ml.scad
3d_printed_parts/utils.scad
3d_printed_parts/x-carriage.scad
3d_printed_parts/y-drivetrain.scad

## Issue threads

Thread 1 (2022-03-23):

Documentation

arisberd, 2022-03-23:
A documentation on constructing and using the device

* Constructing the device
- [x] bill of materials
- [x] 3d printed files
- [x] electronics and wiring
- [x] fritzing diagram
- [x] hardware
- [x] software
- [x] photos
* Using the device
- [x] first setup
- [x] setting up data
- [ ] screenshots

Closed 2023-10-08.

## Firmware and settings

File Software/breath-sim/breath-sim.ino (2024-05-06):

//Infant-breath-mechanical-simulator
//https://github.com/arisberd/Infant-breath-mechanical-simulator
//version 0.3
//GNU GPL v3

// Define stepper motor connections:
#define dirPin 12 // CW
#define stepPin 13 // CLK
#define enaPin 11 // EN

//Define buttons and endstop
#define button_blue_1 5 //changes row (go to next row or to manual-set-row from serial input)
#define button_blue_2 4
#define end_stop 7 //end_stop to the syringe

//Configuration:
//Set this data at the first setup. These are hardware settings.
float calibration_vol = 0.95418 ; // callibration factor of the volume (ex 85/80)
int microsteps = 8; //set the number of microsteps of the stepper motor (ex for 1/4 set to 4, for 1/16 set to 16)
int starting_volume = -6; //the volume beggining from the end stop switch
float steps_to_vol = 3.33 * microsteps * calibration_vol; // 166steps for 50 ml volume. This number is set for 100ml syringe. Changing syringes or motor gear needs adapt of this variable

//variables
float step_count;
int totalsteps;
int point_of_dir_change; //there is only one point where the dir change
int loops_in_round;
float tm ;//60000 /(vol_size * RR); //time interval between values of vol[] , the number in milliseconds
int te_ti_ratio; 
float ti; //inspiration time
float te; //expiration time
int data_max_row_num = 0;
int row_num;
int new_row_set_input = 0;
float ti_corr_f; //ti and te correction factors
float te_corr_f;
unsigned long time_passed[3];
float pause_delay;

//Data from file ... WRITE HERE THE FILE YOU WANT TO  UPLOAD
#include "dataleo_ae_1.h"

//Set last variables of data. Vol_size is defined in datasheets ex. dataleo.h 
float vol[vol_size];
int steps[vol_size];

int pmem_manual_input(int point) {
  int my_int = pgm_read_word_near(manual_input + point);
  return my_int;
}

//Include Serial modes for input and output
#include "serial.h"

void setup() {
  // Declare pins as output:
  pinMode(stepPin, OUTPUT);
  pinMode(dirPin, OUTPUT);
  pinMode(enaPin, OUTPUT);
  pinMode(button_blue_1, INPUT);
  pinMode(button_blue_2, INPUT);
  pinMode(end_stop, INPUT);
  digitalWrite(enaPin, LOW); //disables the stepper driver
  Serial.begin(9600);
  Serial.println("Welcome to Infant breath mechanical simulator!");
  Serial.println("Greece, University Hospiral Of Patras, Pediatric Pulmonology Department, 2021");
  Serial.println("https://github.com/arisberd/Infant-breath-mechanical-simulator");
  Serial.println();
  Serial.println("Blue button 1 - next row");
  Serial.println("Blue button 2 - pause/resume");
  Serial.println("Red button - hard reset");
  Serial.println("You can go to a specific row by writing the row number in the serial monitor and pressing enter. This will take effect after pressing the blue button No1, ex. 5+enter+blue button goes to row 5");
  Serial.println();

  data_max_row_num =  sizeof(manual_input) / sizeof(manual_input[0]) / 3; //setting the maximum number of rows
  print_all_rows();
  Serial.println("Setup finished!!");

  new_row_setup(0);
  Serial.println("First row Start with following");
  print_current();
  Serial.println("Plug in the motor and press the button to start");

  //Button-waits
  while (digitalRead(button_blue_1) == LOW) {  //if the button is not pressed, it waits
    delay (200);
  }
  //moves the motor to the starting position
  digitalWrite(enaPin, HIGH); //enables the stepper driver
  move_motor((steps_to_vol * 120), 3000);
  Serial.println("Starts");
}


void loop() {
  check_buttons(); //includes new_row_setup() which includes calculate_steps()
  
  //inspiration starts
  time_passed[0] = millis(); 
  for (int k = 0; k < insp_curve_point; k++) { 
    if (steps[k] != 0) {
      move_motor(steps[k], ti * ti_corr_f / insp_curve_point);
    }
    else{
      delay (ti * ti_corr_f/ insp_curve_point);
    }
  }
  time_passed[1] = millis(); //end of inspiration 
  
  //expiration starts
  for (int k = insp_curve_point; k<vol_size;k++) {
    if (steps[k] != 0) {
      move_motor(steps[k], te * te_corr_f / (vol_size-insp_curve_point));
    }
    else{
      delay (te * te_corr_f / (vol_size-insp_curve_point));
    }
  }
  time_passed[2] = millis(); //end of expiration

  time_correction(); //corrects small delays because of multiple minor electronic delays
  loops_in_round ++; //counts how many times the loop went in each round

}




void calculate_steps() {
  float rest = 0; //the rest amount of steps if it is not integer

  //Calculating how many steps between vols will make . Steps=number of steps. Rest keeps the 0.numbers
  int totalsteps = 0;
  for (int k = 0; k < vol_size - 1; k++) {
    step_count = steps_to_vol * (vol[k + 1] - vol[k]) + rest;
    rest = step_count - int(step_count);
    steps[k] = int(step_count) * (-1);
    totalsteps = totalsteps + steps[k];
    if (step_count > 0 and point_of_dir_change == 0) point_of_dir_change = k + 1;
  }

  //Calculate the last step
  steps[vol_size - 1] = int(steps_to_vol * (vol[0] - vol[vol_size - 1]) + rest); //the last step is calculated with minus the first, and gives out the rest. Then it is reduced by totalsteps, so in the end the position should be the same
  totalsteps = totalsteps + steps[vol_size - 1];
  if (totalsteps != 0) {
    steps[vol_size - 1] = steps[vol_size - 1] - totalsteps;
  }
  //print_steps_debug();
}






void check_buttons() {
  //Debug
  /*Serial.println("Check Buttons");
    Serial.println(digitalRead(button_blue_1));
    Serial.println(digitalRead(button_blue_2));
    Serial.println(digitalRead(end_stop));
  */

  //Button blue 1 is pushed // change row setup
  if (digitalRead(button_blue_1) == HIGH) {
    int temp_input = serial_input_integer();
    if ((temp_input > 0) and (temp_input != new_row_set_input) and (temp_input <= data_max_row_num)) {
      new_row_set_input = temp_input;
      row_num = new_row_set_input;
      Serial.print("Manualy set round to "); Serial.println(temp_input);
    }
    else {
      row_num ++;
    }
    if (row_num == data_max_row_num) {
      Serial.println("End of experiment. Starts over again");
      delay(3000);
      row_num = 0;
    }
    new_row_setup(row_num);
    Serial.println("Next row Start with following");
    print_current();
    Serial.println("In 0.3 second. Keep pressing the button to skip the round");
    delay (300);
  }


}

void move_motor_delay(int steps_to_move, float time_to_move) {
  //every step takes that much time:time_to_move/steps_to_move
  // These four lines result in 1 step:
  float temp_delay = (1000 * (time_to_move) / (2 * steps_to_move)); // time in microseconds, changed to float VerN
  int temp_delay_milli = temp_delay / 1000; //time in milli sec
  int temp_delay_micro = int(temp_delay) % 1000; //rest of time in micro sec
  digitalWrite(stepPin, HIGH);
  delay(temp_delay_milli);
  delayMicroseconds(temp_delay_micro);
  digitalWrite(stepPin, LOW);
  delay(temp_delay_milli);
  delayMicroseconds(temp_delay_micro);
}



void move_motor (int steps_to_move, float time_to_move) {
  //moves the motor number of steps = steps_to_move, time it takes = time_to_move
  //every step takes that much time:time_to_move/steps_to_move
  //steps_to_move>0 push, steps_to_move < 0 pull
  //During push, checks the end stop
  if (steps_to_move > 0) {
    digitalWrite(dirPin, HIGH);
    delay(6); //must delay to take the signal
    for (int i = 0; (i < steps_to_move) and (digitalRead(end_stop) == 0); i++) {
      pause_module();
      move_motor_delay(steps_to_move, time_to_move);
    }
    if (digitalRead(end_stop) != 0) {
      //Serial.println("Debug - end stop hit");
      move_motor((steps_to_vol * (starting_volume)), 200);
      delay(time_to_move - 200);
    }
  }
  if (steps_to_move < 0) {
    digitalWrite(dirPin, LOW);
    delay(6); //must delay to take the signal
    steps_to_move = -1 * steps_to_move;
    for (int i = 0; i < steps_to_move; i++) {
      pause_module();
      move_motor_delay(steps_to_move, time_to_move);
    }

  }
}

bool paused;
void pause_module() {
  paused = false;
  check_pause_button();
  while (paused == true) {
    delay(100);
    check_pause_button();
    pause_delay += 100;
  }
}



void check_pause_button() {
  //Button blue 2 is pushed //pause button
  if (digitalRead(button_blue_2) == HIGH) {
    bool temp = paused;
    if (temp == false) {
      paused = true;
      Serial.println("Paused!");
    }
    if (temp == true) {
      paused = false;
      Serial.println("Resume!");

    }
    delay(300);
    pause_delay += 300;
  }


}
void time_correction() {
  float last_ti_corr_f = ti_corr_f;//stores last factors
  float last_te_corr_f = te_corr_f;
  int ti_time_passed = time_passed[1] - time_passed[0]; //calculates real ti and te
  int te_time_passed = time_passed[2] - time_passed[1];

  ti_corr_f = last_ti_corr_f * (1 - (ti_time_passed - ti) / ti); //calculates factors
  te_corr_f = last_te_corr_f * (1 - (te_time_passed - te) / te);
}


void new_row_setup(int number_of_row) {

  ti = pmem_manual_input(number_of_row * 3 + 1);
  //vol[1] = pmem_manual_input(number_of_row * 3 + 0); //old version mallon prepei nato sbhso
  calculate_vols(pmem_manual_input(number_of_row * 3 + 0));
  te_ti_ratio = pmem_manual_input(number_of_row * 3 + 2);
  te =  te_ti_ratio * ti / 100;
  calculate_steps ();
  loops_in_round = 0;
  ti_corr_f = 1;
  te_corr_f = 1;

}

void calculate_vols(float maximum_vol) {
  for (int i = 0; i < vol_size; i++) {
    vol[i] = vol_curve[i] / vol_curve_max * maximum_vol ;   
  }
}
